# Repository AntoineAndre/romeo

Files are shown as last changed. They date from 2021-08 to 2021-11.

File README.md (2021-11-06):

# ROMEO PUTAIN Edition

  

Staggered 40% QMK and VIA compatible keyboard pcb assembled with only through hole components, including USB Type-C

**New layout to make a 40%+ keyboard, without changing the edge cuts**
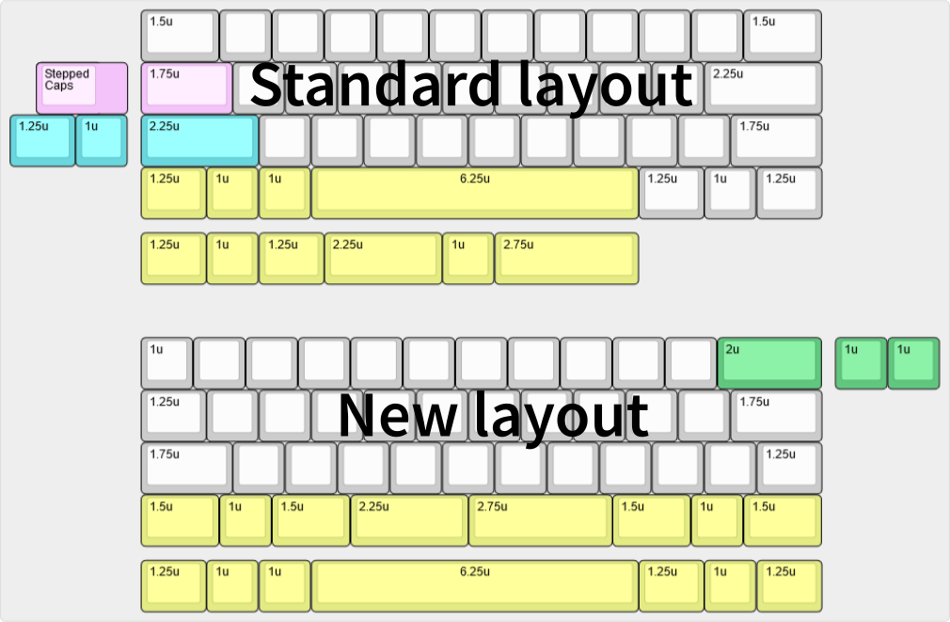
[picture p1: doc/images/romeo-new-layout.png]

Old layout on top and new layout on bottom

**[BOM, Build Guide, and Flashing Information](./doc)**

~~Kits available at [cftkb.com](https://www.cftkb.com)~~

**[Optional High Profile Lasercut Acrylic Case](./case)**

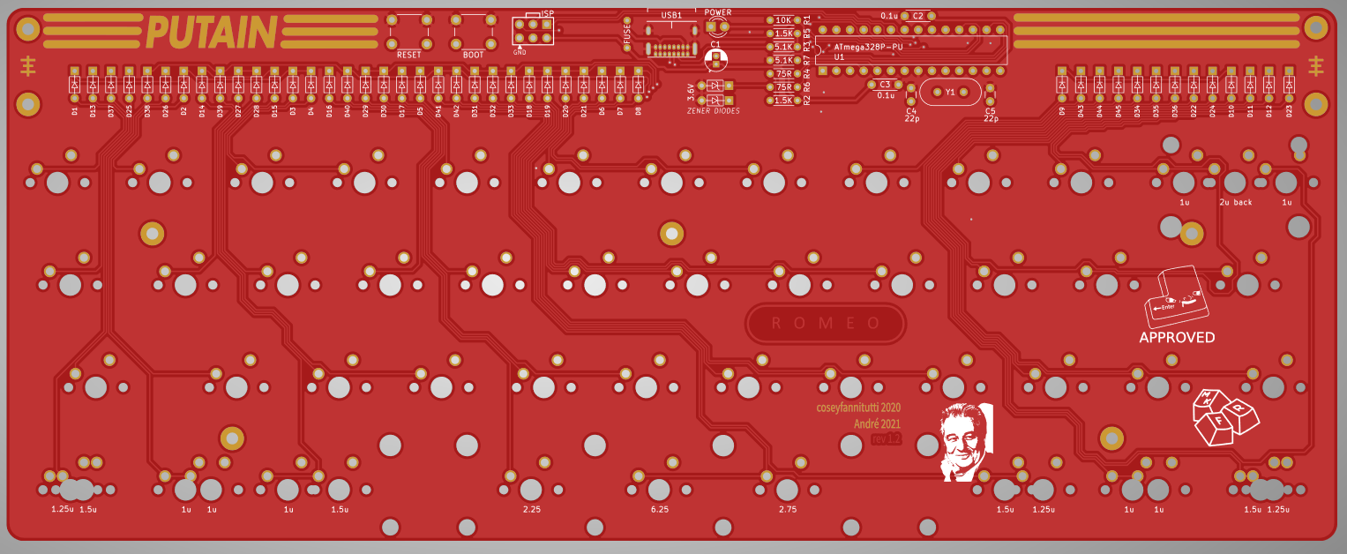
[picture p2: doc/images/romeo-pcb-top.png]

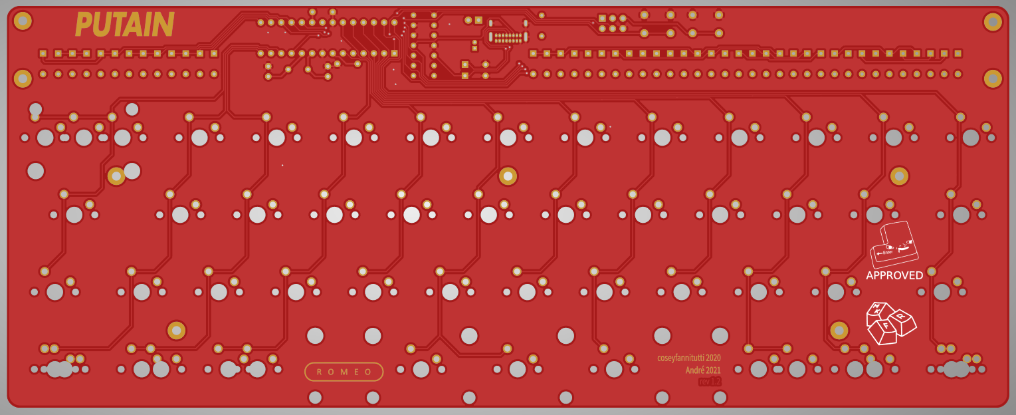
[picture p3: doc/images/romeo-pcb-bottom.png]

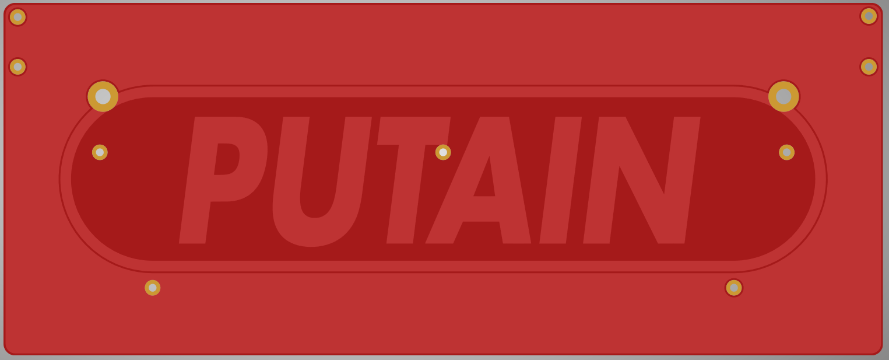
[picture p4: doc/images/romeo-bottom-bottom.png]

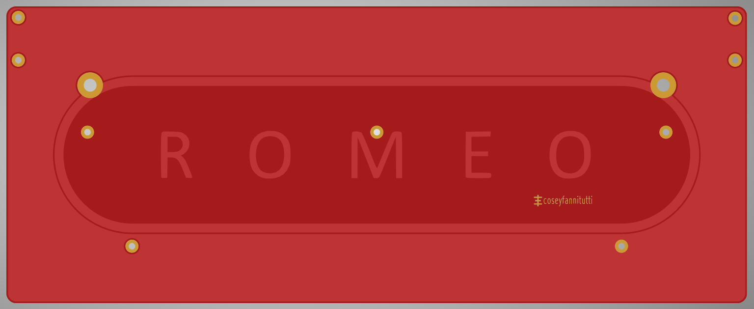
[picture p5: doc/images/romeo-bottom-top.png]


romeo

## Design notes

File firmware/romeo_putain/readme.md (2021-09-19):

# ROMEO

A staggered 40% that can be assembled with only through hole components, including usb type-c, and can also be completely covered with most GMK base kits

* Keyboard Maintainer: [coseyfannitutti](https://github.com/coseyfannitutti)
* Hardware Supported: ROMEO, ATmega328P
* Hardware Availability: [cftkb.com](http://www.cftkb.com), [GitHub](https://github.com/coseyfannitutti/romeo)

Make example for this keyboard (after setting up your build environment):

    make coseyfannitutti/romeo:default

See the [build environment setup](https://docs.qmk.fm/#/getting_started_build_tools) and the [make instructions](https://docs.qmk.fm/#/getting_started_make_guide) for more information. Brand new to QMK? Start with our [Complete Newbs Guide](https://docs.qmk.fm/#/newbs).

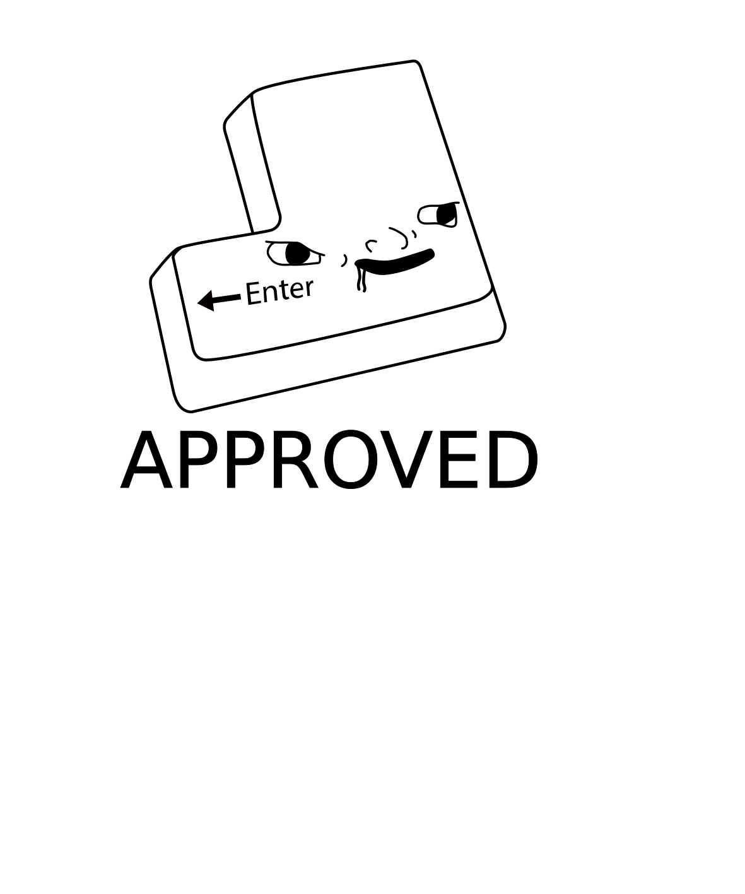
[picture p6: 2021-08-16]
perso_silks/.svg2shenzhen-cache/images/F.SilkS_g925.png

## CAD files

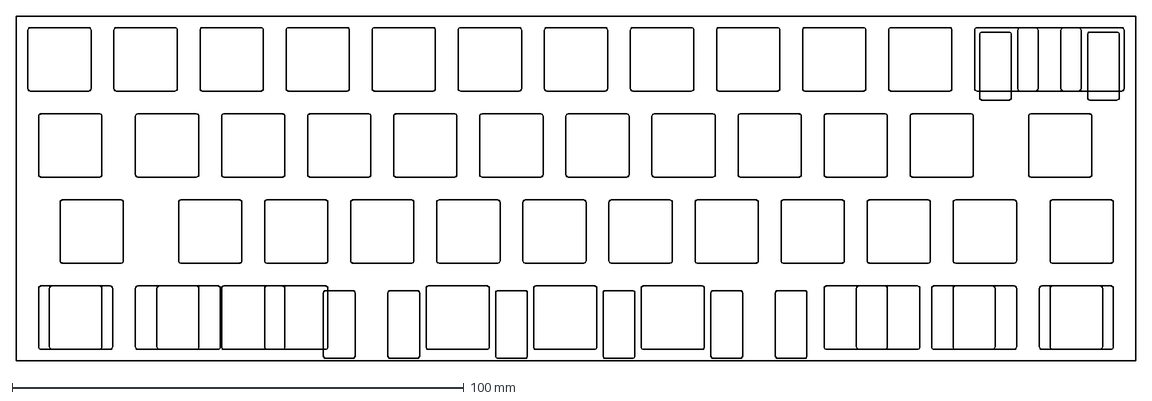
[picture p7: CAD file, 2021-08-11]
plate/romeo_generated_switch_plate.dxf
247.7 x 76.2 mm

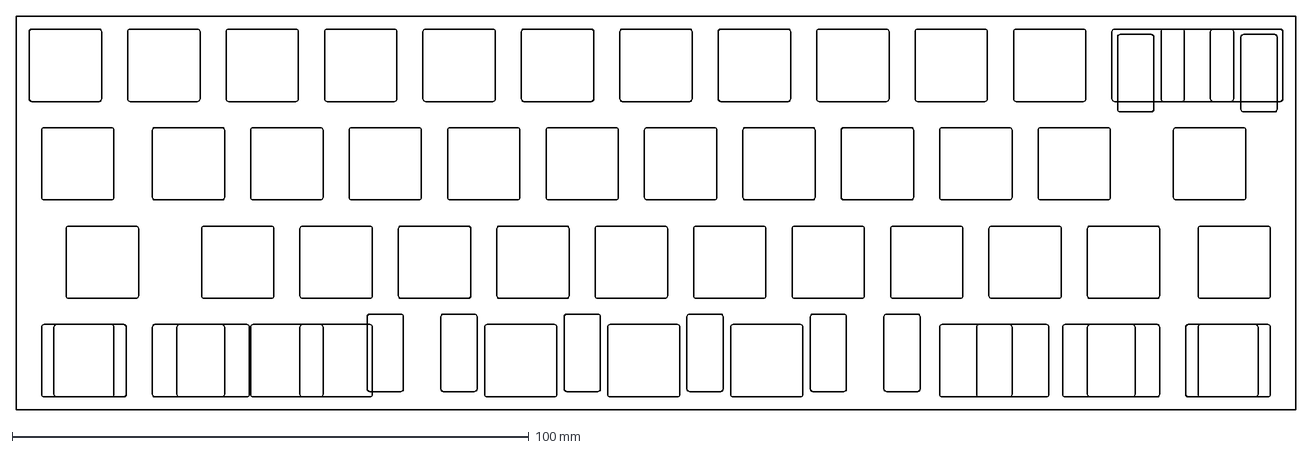
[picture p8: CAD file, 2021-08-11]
plate/romeo_generated_switch_plate_rs.dxf
247.7 x 76.2 mm

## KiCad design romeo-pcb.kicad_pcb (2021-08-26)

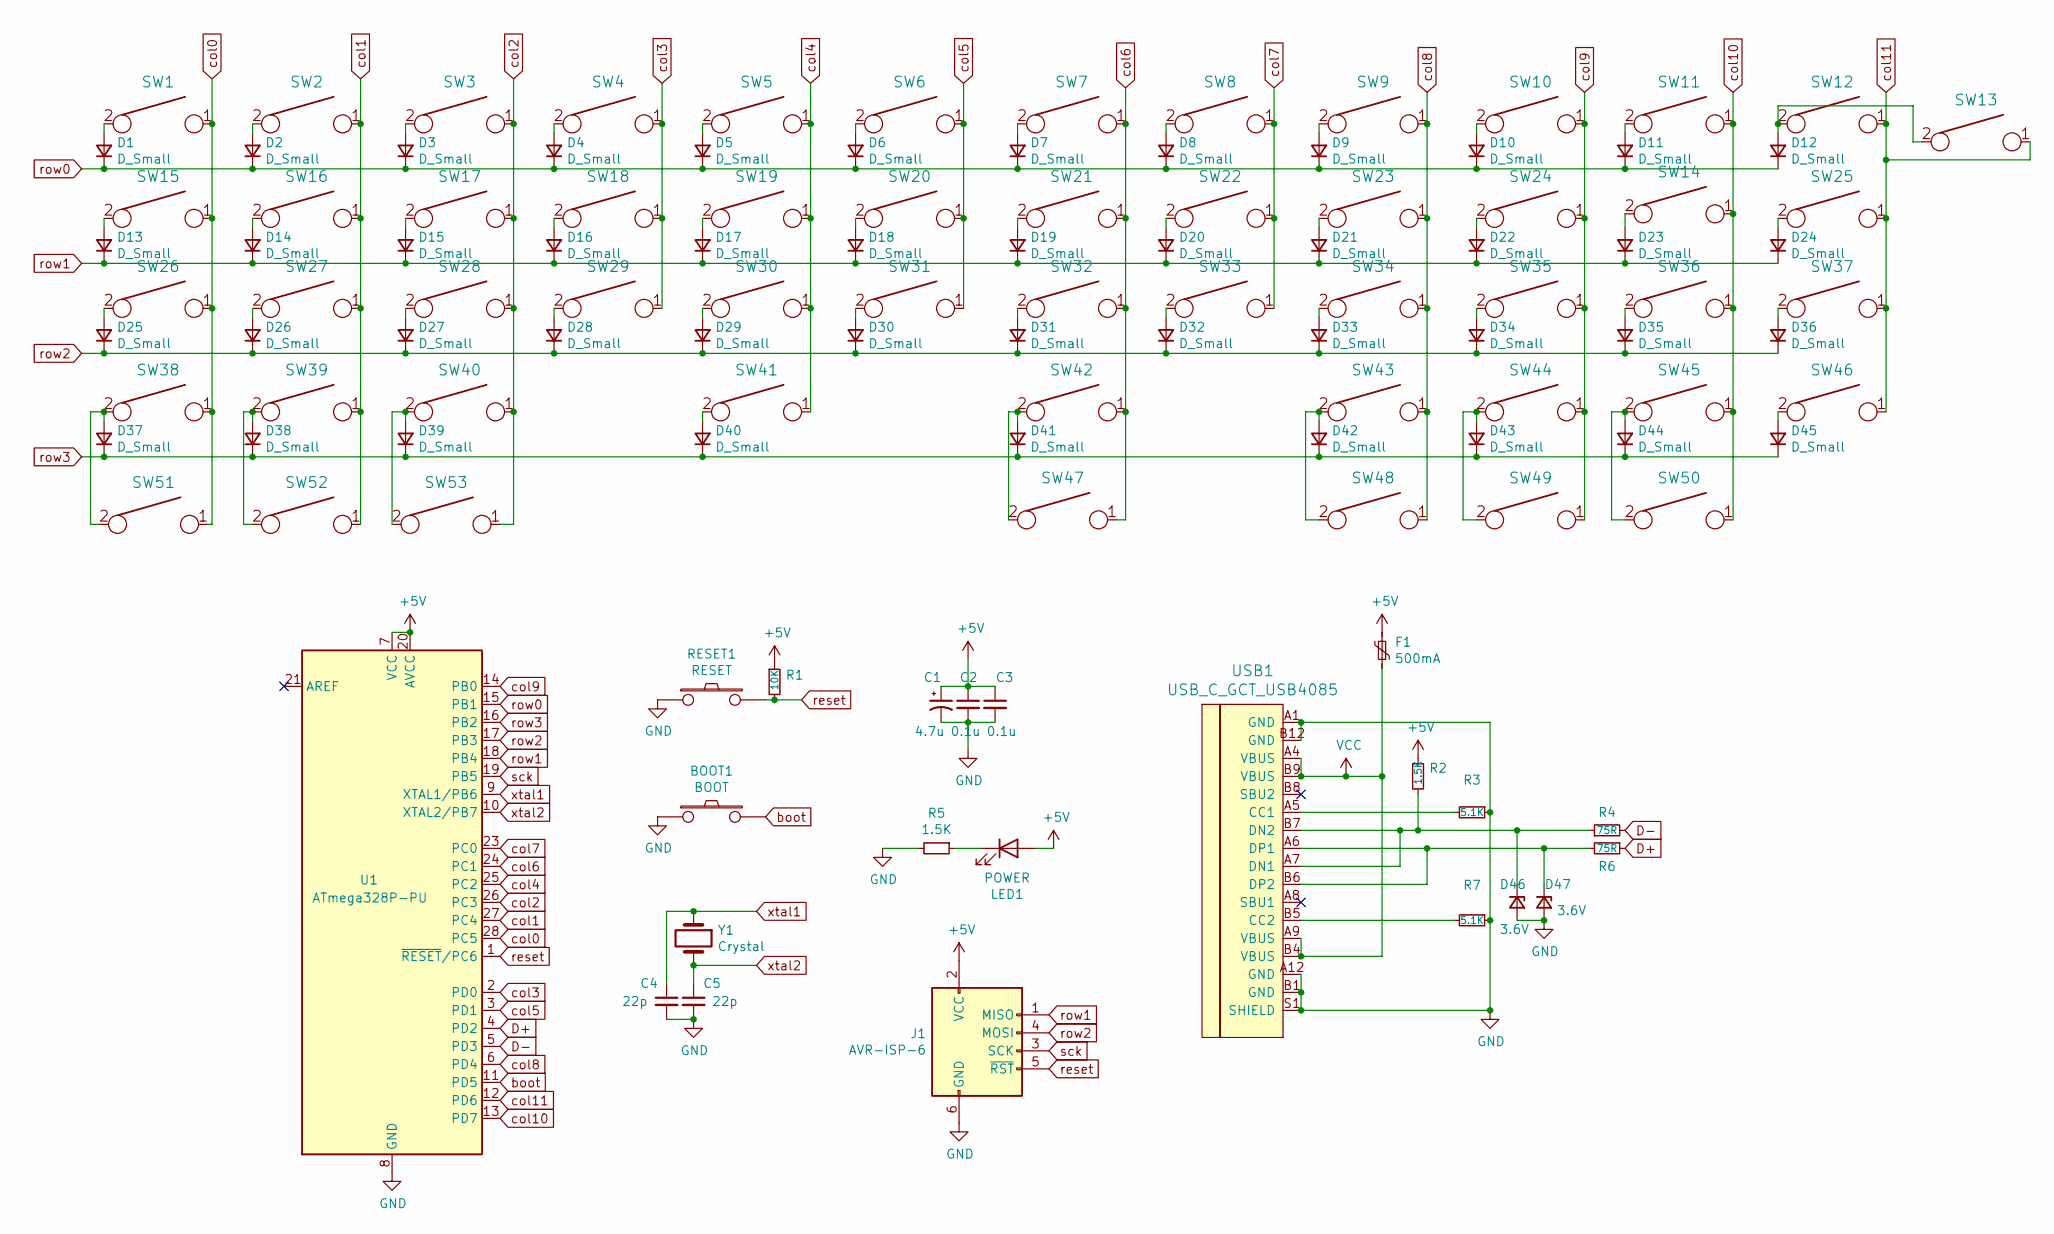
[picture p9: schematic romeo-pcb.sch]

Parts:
BOOT1: BOOT; SW_PUSH_6mm
C1: 4.7u; CP_Radial_D4.0mm_P1.50mm
C2, C3: 0.1u; C_Disc_D4.3mm_W1.9mm_P5.00mm
C4, C5: 22p; C_Disc_D3.0mm_W1.6mm_P2.50mm
D1, D2, D3, D4, D5, D6, D7, D8, D9, D10, D11, D12, D13, D14, D15, D16, D17, D18, D19, D20, D21, D22, D23, D24, D25, D26, D27, D28, D29, D30, D31, D32, D33, D34, D35, D36, D37, D38, D39, D40, D41, D42, D43, D44, D45: D_Small; D_DO-35_SOD27_P5.08mm_Horizontal
D46, D47: 3.6V; D_DO-35_SOD27_P5.08mm_Horizontal
F1: 500mA; polyfuse_5.1mm
J1: AVR-ISP-6; AVR_ICSP_3x2
LED1: POWER; LED_D3.0mm
R1: 10K; R_Axial_DIN0204_L3.6mm_D1.6mm_P5.08mm_Horizontal
R2, R5: 1.5K; R_Axial_DIN0204_L3.6mm_D1.6mm_P5.08mm_Horizontal
R3, R7: 5.1K; R_Axial_DIN0204_L3.6mm_D1.6mm_P5.08mm_Horizontal
R4, R6: 75R; R_Axial_DIN0204_L3.6mm_D1.6mm_P5.08mm_Horizontal
RESET1: RESET; SW_PUSH_6mm
SW1, SW2, SW3, SW4, SW5, SW6, SW7, SW8, SW9, SW10, SW11, SW12, SW14, SW16, SW17, SW18, SW19, SW20, SW21, SW22, SW23, SW24, SW27, SW28, SW29, SW30, SW31, SW32, SW33, SW34, SW35, SW36, SW39, SW44, SW46, SW49, SW52, SW53: KEYSW; SW_Cherry_MX1A_1.00u_PCB-NOSCREEN
SW13: KEYSW; SW_Cherry_MX1A_2.00u_PCBNOSCREEN
SW15, SW37, SW48, SW50, SW51: KEYSW; SW_Cherry_MX1A_1.25u_PCBNOSCREEN
SW25, SW26: KEYSW; SW_Cherry_MX1A_1.75u_PCBNOSCREEN
SW38, SW40, SW43, SW45: KEYSW; SW_Cherry_MX1A_1.50u_PCBNOSCREEN
SW41: KEYSW; SW_Cherry_MX1A_2.25u_PCBNOSCREEN
SW42: KEYSW; MXOnly-2.75U-ReversedStabilizers-NoLED
SW47: KEYSW; MXOnly-6.25U-ReversedStabilizers-NoLED
U1: ATmega328P-PU; DIP-28_W7.62mm
USB1: USB_C_GCT_USB4085
Y1: Crystal; Crystal_HC49-4H_Vertical

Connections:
+5V: C1.1, C2.1, C3.1, F1.1, J1.2 (VCC), LED1.2 (A), R1.1, R2.1, U1.7 (VCC), U1.20 (AVCC)
D+: R6.1, U1.4 (PD2)
D-: R4.2, U1.5 (PD3)
GND: BOOT1.1, C1.2, C2.2, C3.2, C4.2, C5.2, D46.2 (A), D47.2 (A), J1.6 (GND), R3.1, R5.2, R7.1, RESET1.1, U1.8 (GND), U1.22 (GND), USB1.A1 (GND), USB1.A12 (GND), USB1.B1 (GND), USB1.B12 (GND), USB1.S1 (SHIELD)
unnamed: D1.2 (A), SW1.2
unnamed: D2.2 (A), SW2.2
unnamed: D3.2 (A), SW3.2
unnamed: D4.2 (A), SW4.2
unnamed: D5.2 (A), SW5.2
unnamed: D6.2 (A), SW6.2
unnamed: D7.2 (A), SW7.2
unnamed: D8.2 (A), SW8.2
unnamed: D9.2 (A), SW9.2
unnamed: D10.2 (A), SW10.2
unnamed: D11.2 (A), SW11.2
unnamed: D12.2 (A), SW12.2, SW13.2
unnamed: D13.2 (A), SW15.2
unnamed: D14.2 (A), SW16.2
unnamed: D15.2 (A), SW17.2
unnamed: D16.2 (A), SW18.2
unnamed: D17.2 (A), SW19.2
unnamed: D18.2 (A), SW20.2
unnamed: D19.2 (A), SW21.2
unnamed: D20.2 (A), SW22.2
unnamed: D21.2 (A), SW23.2
unnamed: D22.2 (A), SW24.2
unnamed: D23.2 (A), SW14.2
unnamed: D24.2 (A), SW25.2
unnamed: D25.2 (A), SW26.2
unnamed: D26.2 (A), SW27.2
unnamed: D27.2 (A), SW28.2
unnamed: D28.2 (A), SW29.2
unnamed: D29.2 (A), SW30.2
unnamed: D30.2 (A), SW31.2
unnamed: D31.2 (A), SW32.2
unnamed: D32.2 (A), SW33.2
unnamed: D33.2 (A), SW34.2
unnamed: D34.2 (A), SW35.2
unnamed: D35.2 (A), SW36.2
unnamed: D36.2 (A), SW37.2
unnamed: D37.2 (A), SW38.2, SW51.2
unnamed: D38.2 (A), SW39.2, SW52.2
unnamed: D39.2 (A), SW40.2, SW53.2
unnamed: D40.2 (A), SW41.2
unnamed: D41.2 (A), SW42.2, SW47.2
unnamed: D42.2 (A), SW43.2, SW48.2
unnamed: D43.2 (A), SW44.2, SW49.2
unnamed: D44.2 (A), SW45.2, SW50.2
unnamed: D45.2 (A), SW46.2
unnamed: D46.1 (K), R2.2, R4.1, USB1.A7 (DN1), USB1.B7 (DN2)
unnamed: D47.1 (K), R6.2, USB1.A6 (DP1), USB1.B6 (DP2)
unnamed: LED1.1 (K), R5.1
unnamed: R3.2, USB1.A5 (CC1)
unnamed: R7.2, USB1.B5 (CC2)
VCC: F1.2, USB1.A4 (VBUS), USB1.A9 (VBUS), USB1.B4 (VBUS), USB1.B9 (VBUS)
boot: BOOT1.2, U1.11 (PD5)
col0: SW1.1, SW15.1, SW26.1, SW38.1, SW51.1, U1.28 (PC5)
col1: SW2.1, SW16.1, SW27.1, SW39.1, SW52.1, U1.27 (PC4)
col2: SW3.1, SW17.1, SW28.1, SW40.1, SW53.1, U1.26 (PC3)
col3: SW4.1, SW18.1, SW29.1, U1.2 (PD0)
col4: SW5.1, SW19.1, SW30.1, SW41.1, U1.25 (PC2)
col5: SW6.1, SW20.1, SW31.1, U1.3 (PD1)
col6: SW7.1, SW21.1, SW32.1, SW42.1, SW47.1, U1.24 (PC1)
col7: SW8.1, SW22.1, SW33.1, U1.23 (PC0)
col8: SW9.1, SW23.1, SW34.1, SW43.1, SW48.1, U1.6 (PD4)
col9: SW10.1, SW24.1, SW35.1, SW44.1, SW49.1, U1.14 (PB0)
col10: SW11.1, SW14.1, SW36.1, SW45.1, SW50.1, U1.13 (PD7)
col11: SW12.1, SW13.1, SW25.1, SW37.1, SW46.1, U1.12 (PD6)
reset: J1.5 (~RST), R1.2, RESET1.2, U1.1 (~RESET~/PC6)
row0: D1.1 (K), D2.1 (K), D3.1 (K), D4.1 (K), D5.1 (K), D6.1 (K), D7.1 (K), D8.1 (K), D9.1 (K), D10.1 (K), D11.1 (K), D12.1 (K), U1.15 (PB1)
row1: D13.1 (K), D14.1 (K), D15.1 (K), D16.1 (K), D17.1 (K), D18.1 (K), D19.1 (K), D20.1 (K), D21.1 (K), D22.1 (K), D23.1 (K), D24.1 (K), J1.1 (MISO), U1.18 (PB4)
row2: D25.1 (K), D26.1 (K), D27.1 (K), D28.1 (K), D29.1 (K), D30.1 (K), D31.1 (K), D32.1 (K), D33.1 (K), D34.1 (K), D35.1 (K), D36.1 (K), J1.4 (MOSI), U1.17 (PB3)
row3: D37.1 (K), D38.1 (K), D39.1 (K), D40.1 (K), D41.1 (K), D42.1 (K), D43.1 (K), D44.1 (K), D45.1 (K), U1.16 (PB2)
sck: J1.3 (SCK), U1.19 (PB5)
xtal1: C4.1, U1.9 (XTAL1/PB6), Y1.1
xtal2: C5.1, U1.10 (XTAL2/PB7), Y1.2

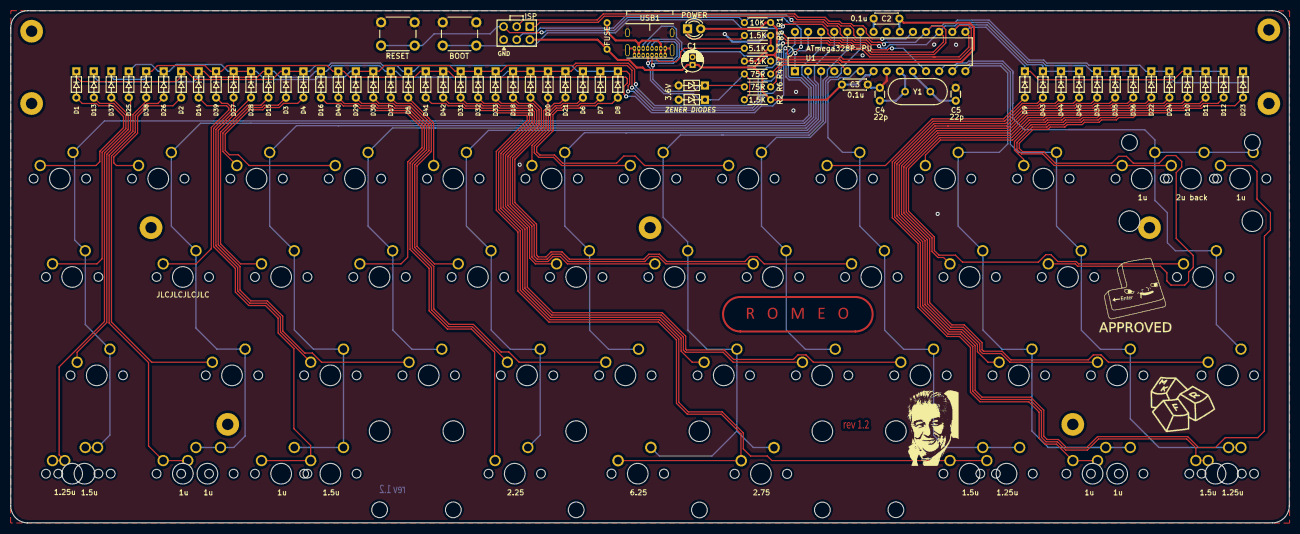
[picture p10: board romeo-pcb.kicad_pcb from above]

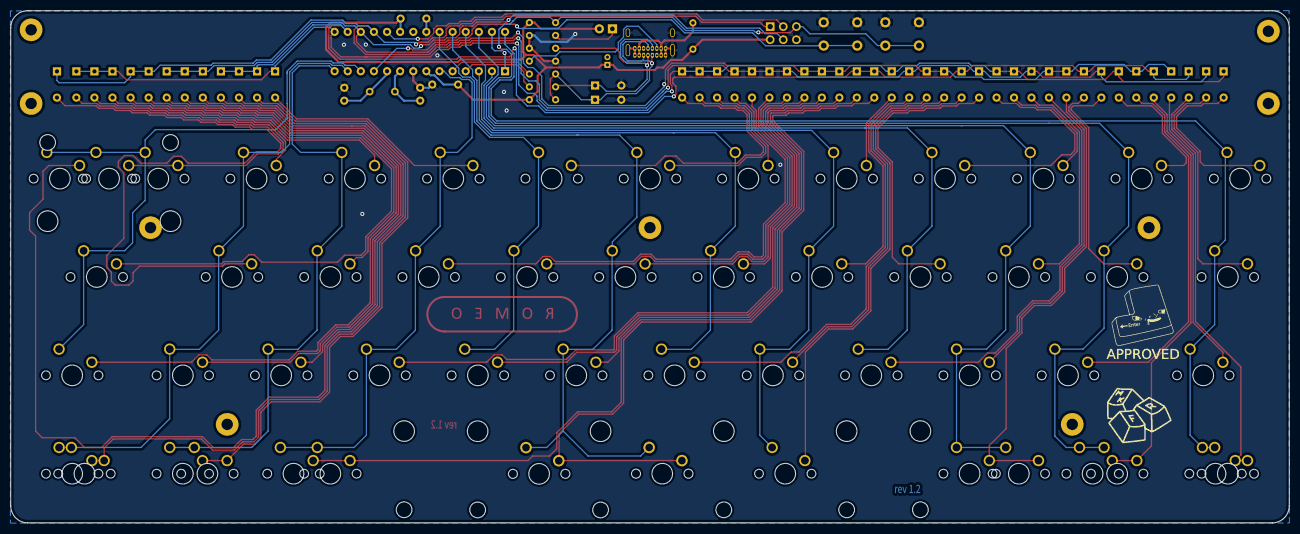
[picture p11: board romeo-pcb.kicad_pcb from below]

Board: 2 copper layers, 247.6 x 99.2 mm, 130 parts (5 on the bottom side), 76 nets.

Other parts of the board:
Ref**: Val**; golmon_silk_svg
Ref**#2: Val**; golmon_silk_svg
Ref**#3, Ref**#6: Val**; putain_svg
Ref**#4, Ref**#5: Val**; mkfr_footprint
Ref**#7, Ref**#10: Val**; rev_num
Ref**#8, Ref**#9: Val**; author_footprint

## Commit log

2021-08-11 Add new layout to romeo keyboard
    Add the new layout (based on CC45) to make the keyboard more convenient to use
    Update footprints to match this rev1.2
    [rev_num.dxf, romeo-pcb.kicad_pcb, romeo-pcb.sch]
2021-08-11 Add switch plate
    [romeo-pcb.kicad_pcb, romeo_generated_switch_plate.dxf, romeo_generated_switch_plate_rs.dxf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]
2021-08-16 Update silks and gerbers
    [romeo-bottom-B_Cu.gbr, romeo-bottom-B_Mask.gbr, romeo-bottom-B_SilkS.gbr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]
2021-08-26 Update gerbers, sent a first command to jlcpcb
    [romeo-bottom-B_Cu.gbr, romeo-bottom-B_Mask.gbr, romeo-bottom-B_SilkS.gbr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]
